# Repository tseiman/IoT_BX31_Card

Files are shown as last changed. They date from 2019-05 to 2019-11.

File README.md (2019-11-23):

# IoT BX31 Card

IoT card for Sierra Wireless MangOH (https://mangoh.io) boards.
Connects the Sierra Wirelss  BX3105 Module via UART to the (WP) Module.
The IoT card is easy to use by using the Legato (https://legato.io) AT command interpreter.

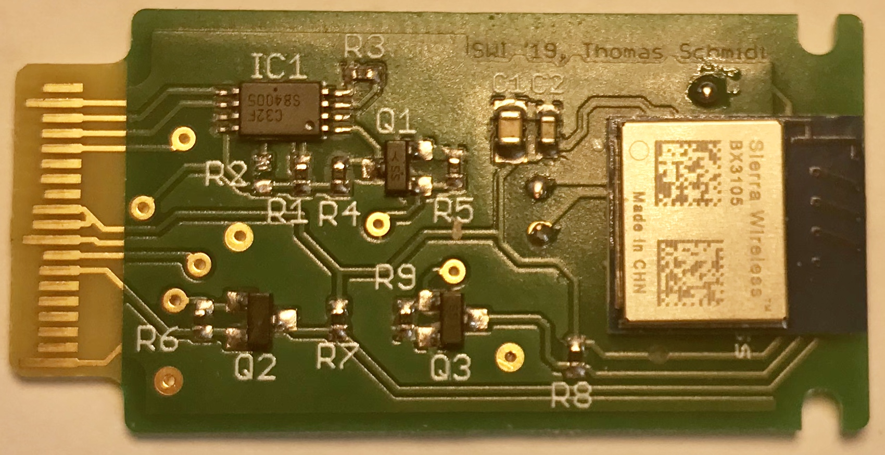
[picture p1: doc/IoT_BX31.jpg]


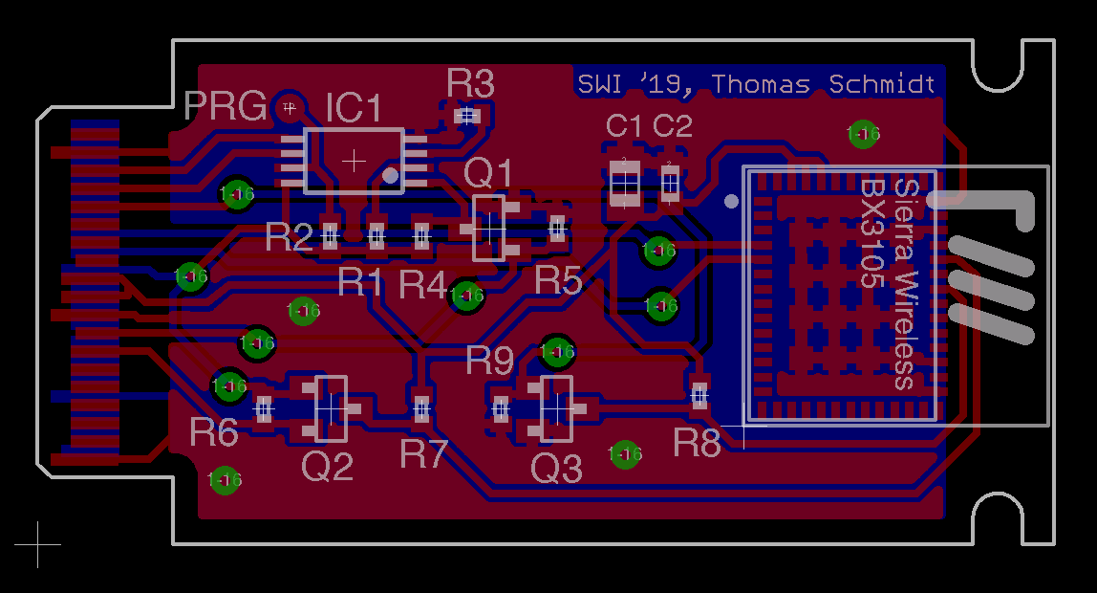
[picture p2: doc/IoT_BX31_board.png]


## Programming the EEPROM
After hardware production the EEPROM needs to be one time flashed with the Identity and configuration data of the IoT card.
Please see the eeprom folder for further information. 

## Basic testing on MangOH
Ensure that the UART of the WP module is configured correctly to handle the IoT module - e.g. by configuring it via `AT!MAPUART=17,1` command on the WP module (please cross check the WP AT User guide).
**Ensure that the GPIO's are set correctly**. On MangOH red this are GPIO 42 for Firmware update and GPIO 2 for enable. The BX31 IoT module supports update of the Firmware over UART by pulling GPIO 42 low (it is a Active Low Pin on BX3105). For normal operation **pull GPIO42 high (important)**. To reset the card you need to pull "enable" GPIO 2  High and then pull it down again - so the BX3105 gets enabled.

Disable Firmware update GPIO from command line:
```
~# echo 42 >/sys/class/gpio/export
~# echo out >/sys/class/gpio/gpio42/direction
~# echo 0 > /sys/class/gpio/gpio42/value
```
Reset the Module:
```
~# echo 2 >/sys/class/gpio/export
~# echo out >/sys/class/gpio/gpio2/direction
~# echo 1 > /sys/class/gpio/gpio2/value
~# echo 0 > /sys/class/gpio/gpio2/value
```

Now you can connect to the UART by using microcom and it should react to BX31 AT commands:
```
~# microcom -X -s 115200 /dev/ttyHS0
ATI

BX3105

OK
```
You can exit microcom by pressing **CTRL-X**. Please remember that when typing AT commands you'll not see what you type becasue BX31 are not echoing back. 

You can also read the content of the IoT card EEPROM, by reading it over I2C with i2cdump:

```
TBD
```

## Using it the IoT card in Legato

Ensure the UART of the WP module is configured in the right way. On a WP76 this can be done with the `AT!MAPUART=17,1` command. 
For further Information check the AT command guide of the Module you plan to use. 
The IoT module will be then accessible over the `/dev/ttyHS0` UART in Legato.
You might do this setoup out of a Legato application by using the Legato AT interpreter API.

In case you plan to use the BX31 IoT module in an Legato environment and to control it from a Legato Application - ensure that you have read/write access to the device.
This can be configured in the **requires - devices** section of your Legato appliactions **.adef** file - e.g.:

```
requires:
{
    device:
    {
       [rw]    /dev/ttyHS0    /dev/ttyHS0
    }
}

```

Ensure in the same file that you bind the AT Interpreter API to your project:

```
bindings:
{
    bx31_atservice.BX31_ATServiceComponent.le_atClient -> atService.le_atClient
...    
}
```

Now you can use the API to control the BX31 IoT Board - see this snippeds as some example (more glue code might be needed):

```c
        fd = le_tty_Open(BX31_SERIAL_DEVICE, O_RDWR | O_NDELAY | O_NOCTTY | O_NONBLOCK); // opening the UART2 - which is connected to the IoT Board
        if (fd == -1) {
                LE_ERROR("failed to open UART device");
                exit(EXIT_FAILURE);
        }
        
       ...

        LE_ASSERT(le_tty_SetBaudRate(fd, LE_TTY_SPEED_115200) == LE_OK);        // assuming BX31 is on 115200
        LE_ASSERT(le_tty_SetFraming(fd, 'N', 8, 1) == LE_OK);                   // set UART framing to 8bit, No Parity, 1 Stop bit
        LE_ASSERT(le_tty_SetRaw(fd, 10, 30000) == LE_OK);                       // We need raw UART mode (the canonical echo's
                                                                                // back to peer)
       ...

        DevRef = le_atClient_Start(fd);

        cmdRef = le_atClient_Create();                                          // instantiate an AT interpreter client

        /* --- check if we're really talking to BX31 --- */
        LE_INFO("Check BX310x presence");                                       // We ask for device identification string

        LE_ASSERT(le_atClient_SetCommandAndSend
                  (&cmdRef, DevRef, "ATI", "", "OK|ERROR|+CME ERROR",
                   LE_ATDEFS_COMMAND_DEFAULT_TIMEOUT) == LE_OK);

        LE_ASSERT(le_atClient_GetFinalResponse
                  (cmdRef, buffer, LE_ATDEFS_RESPONSE_MAX_BYTES) == LE_OK);

        memset(buffer, 0, 50);

        LE_ASSERT(le_atClient_GetFirstIntermediateResponse
                  (cmdRef, buffer, LE_ATDEFS_RESPONSE_MAX_BYTES) == LE_OK);

        if (strncmp(buffer, "BX310", 4) != 0) {                                 // and compare it with the expected
                LE_ERROR("This doesn seem to be a BX310x bluetooth module, "
                                "exiting. Response was \"%s\"", buffer);        // if the BT module is not answering we better exit

      ...

        LE_INFO("Disable WiFi on BX310x");                                      // here we use the BX just for BT scanning
        LE_ASSERT(le_atClient_SetCommandAndSend
                  (&cmdRef, DevRef, "AT+SRWCFG=0", "", "OK|ERROR|+CME ERROR",
                   LE_ATDEFS_COMMAND_DEFAULT_TIMEOUT) == LE_OK);

``` 

For further information please check the legato AT API https://docs.legato.io/17_09/c_atClient.html
There is also a project related to this IoT Board which is used to do a bluetooth scanning: 
https://github.com/tseiman/SWILegatoBTScanner_BX31_AVS

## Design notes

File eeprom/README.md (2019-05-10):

**eeprom_iot_bx31_card.yaml** is a template file from which the IoT Card EEPROM image can be generated.

The image is only one time flashed to give the IoT Module it's identity and configuration parameters which might be read by a Legato Application or Kernel driver.

The yaml to EEPROM bin image conversion tool can be found from here:

https://github.com/mangOH/mangOH/tree/master/tools

The **writeFile2Eeprom** tool has to be cross compiled in a Legato legs environment and is meant to run directly on a WP module - in case the EEPROM is not flashed during production.

Clone and `make` Legato according to the advises from here: https://github.com/legatoproject/legato-af .

Run the Legato bin/legs environment. Change to this directory and check the Makefile. 
Adjust the Variables:

* $(WP76XX_SYSROOT)
* $(WP76XX_TOOLCHAIN_PREFIX)
* $(WP76XX_TOOLCHAIN_DIR)

At the moment it is set to be compiled for Sierra Wireless WP76XX modules. You might adjust it e.g. to
$(WP77XX_TOOLCHAIN_DIR) or similar for an other module series.

Compile the **writeFile2Eeprom** by `make` in this folder. 

Copy the compiled **writeFile2Eeprom** e.g. by `~> scp writeFile2Eeprom root@192.168.2.2:~`.

Insert a new, unflashed IoT card into the IoT slot of a MangOH board. 
Enable the EEPROM to write. For that the WP Signal of the EEPROM needs to be pulled down. On BX31 IoT Board hardware revision 1.0 the wire 
between R5 and the EEPROM has to be conencted to GND. On newer hardware revisions there is a testpoint which needs to be connected to GND.

Run **writeFile2Eeprom** with a correct set of parameters:

```
writeFile2Eeprom [-b <busID>] -f <eeprom image input file> [-y] -s <IoT card serial Number>
    -b <busID>                     optional,  the I2C bus ID - on MangOH red it is 5 (default)
    -f <eeprom image input file>   mandatory, the image which should be written to eeprom
    -y 	                           optional,  it will not ask if you are really sure
    -s <IoT Serial Number>         mandatory, a string with max 31 bytes with the serial information
                                   of the IoT card. BX31 IoT card SN should have following format:
                                   YYYYMMDDhhmmss_<HW Version>_<NumberInBatch> e.g.: 20190506200700_1.0_001
```

e.g.: `~> writeFile2Eeprom -b 5 -f eeprom_iot_bx31_card.img -s 20190506200700_1.0_001`

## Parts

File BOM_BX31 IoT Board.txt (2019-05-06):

Stückliste exportiert aus /Users/tseiman/Documents/eagle/BX3105 IoT card/BX31 IoT Board.sch am 06.05.19 12:54

Qty Value                       Device     Package Parts                              Description                                                                   MF MPN            OC_FARNELL OC_NEWARK TP_SIGNAL_NAME
1                               C-EUC0603K C0603K  C2                                 CAPACITOR, European symbol                                                                                                         
9   10k                         R-EU_R0402 R0402   R1, R2, R3, R4, R5, R6, R7, R8, R9 RESISTOR, European symbol                                                                                                          
1   22u                         C-EUC0805K C0805K  C1                                 CAPACITOR, European symbol                                                                                                         
3   BSS138                      BSS123     SOT23   Q1, Q2, Q3                         N-CHANNEL MOS FET                                                                                                                  
1   BX3105                      BX3105     BX3105  MODULE1                            The BX310x is a low power, 802.11 b/g/n Wi-Fi and Bluetooth 4.2 combo module.                                                      
1   CAT24C32             YI-GT3 24C64ST    TSSOP8  IC1                                Serial EEPROM                                                                    CAT24C64YI-GT3 1718133    08R5418                 
1   IOT                         IOT        IOT     U$1                                IoT Expansion Card                                                                                                                 
1   TPSB1,27                    TPSB1,27   B1,27   PRG                                TEST PIN

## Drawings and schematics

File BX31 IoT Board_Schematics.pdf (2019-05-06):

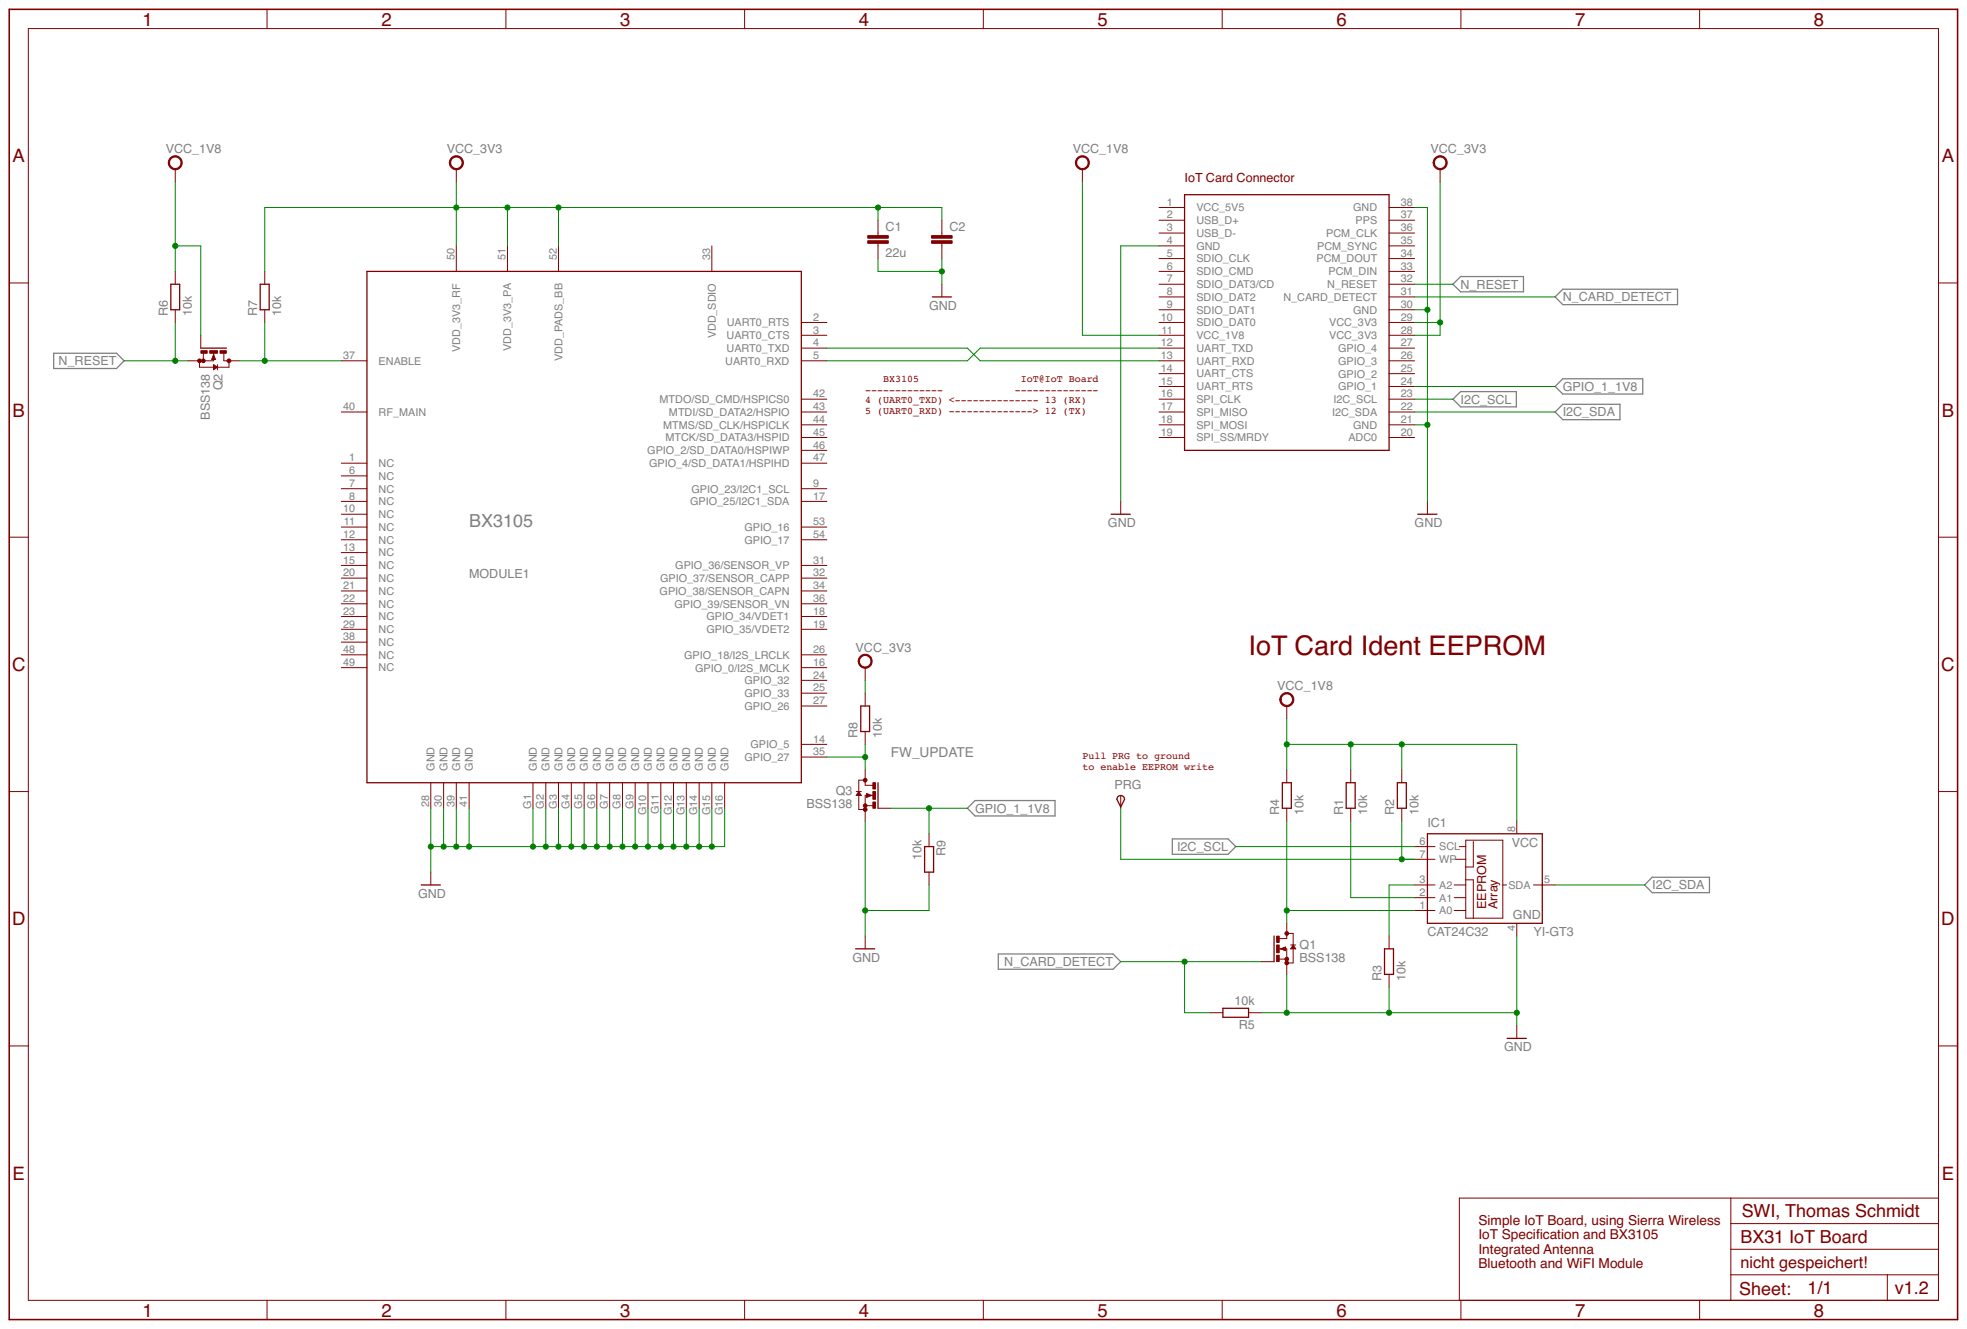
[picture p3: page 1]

IoT Card Ident EEPROM

41 GND G1 GND G2 GND G3 GND G4 GND G5 GND G6 GND G7 GND G8 GND G9 GND G11 GND G10 GND G12 GND G13 GND G14 GND G15 GND G16 GPIO_27

Pull PRG to ground
to enable EEPROM write
PRG

SWI, Thomas Schmidt Simple IoT Board, using Sierra Wireless
IoT Specification and BX3105
Integrated Antenna Bluetooth and WiFI Module

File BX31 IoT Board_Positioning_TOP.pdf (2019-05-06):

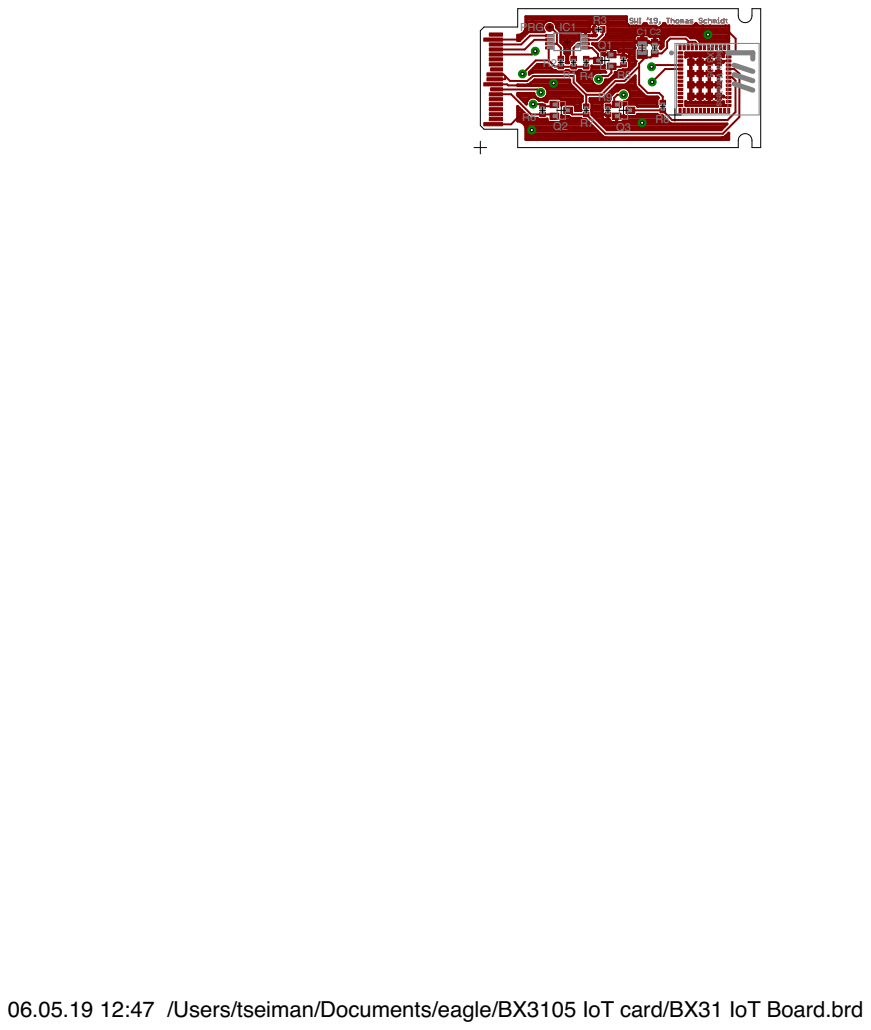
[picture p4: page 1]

06.05.19 12:47 /Users/tseiman/Documents/eagle/BX3105 IoT card/BX31 IoT Board.brd

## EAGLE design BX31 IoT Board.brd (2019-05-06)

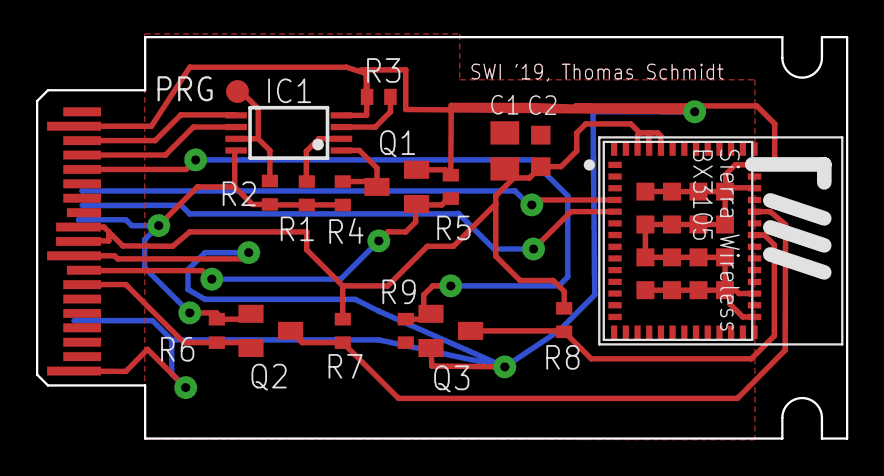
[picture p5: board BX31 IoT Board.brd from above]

Board: 2 copper layers, 45.0 x 22.3 mm, 18 parts (0 on the bottom side), 16 nets.

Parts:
C1: 22u; C0805K
C2: C0603K
IC1: CAT24C32 YI-GT3; TSSOP8
MODULE1: BX3105
PRG: TPSB1,27; B1,27
Q1, Q2, Q3: BSS138; SOT23
R1, R2, R3, R4, R5, R6, R7, R8, R9: 10k; R0402
U$1: IOT

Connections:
BX-RX_IOT-TX: MODULE1.5, U$1.12
BX-TX_IOT-RX: MODULE1.4, U$1.13
EEPROM_A0: IC1.1, Q1.3, R4.1
EEPROM_A1: IC1.2, R1.1
EEPROM_A2: IC1.3, R3.2
EEPROM_WP: IC1.7, PRG.TP, R2.1
ENABLE: MODULE1.37, Q2.3, R7.1
FW_UPDATE: MODULE1.35, Q3.3, R8.1
GND: C1.2, C2.2, IC1.4, MODULE1.28, MODULE1.30, MODULE1.39, MODULE1.41, MODULE1.G1, MODULE1.G2, MODULE1.G3, MODULE1.G4, MODULE1.G5, MODULE1.G6, MODULE1.G7, MODULE1.G8, MODULE1.G9, MODULE1.G10, MODULE1.G11, MODULE1.G12, MODULE1.G13, MODULE1.G14, MODULE1.G15, MODULE1.G16, Q1.2, Q3.2, R3.1, R5.1, R9.2, U$1.4, U$1.21, U$1.30, U$1.38
GPIO_1_1V8: Q3.1, R9.1, U$1.24
I2C_SCL: IC1.6, U$1.23
I2C_SDA: IC1.5, U$1.22
N_CARD_DETECT: Q1.1, R5.2, U$1.31
N_RESET: Q2.2, R6.1, U$1.32
VCC_1V8: IC1.8, Q2.1, R1.2, R2.2, R4.2, R6.2, U$1.11
VCC_3V3: C1.1, C2.1, MODULE1.50, MODULE1.51, MODULE1.52, R7.2, R8.2, U$1.28, U$1.29

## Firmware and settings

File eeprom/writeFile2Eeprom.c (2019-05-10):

/**
 * by Thomas Schmidt Fr 09 Mai 2019 22:59:50 CEST
 * Tool to write the IoT EEPROM directly on an MangOH board.
 * EEPROM Write needs to be enabled (see IoT Board Readme and tool Readme)
 *
 **/


#include <unistd.h>
#include <stdio.h>
#include <stdlib.h>
#include <linux/i2c-dev.h>
#include <linux/limits.h>
#include <sys/ioctl.h>
#include <sys/types.h>
#include <sys/stat.h>
#include <fcntl.h>
#include <ctype.h>
#include <string.h>


#define DEFAULT_MANGOH_RED_IOT_I2C_BUS_ID	5
#define I2C_BASE_PATH				"/dev/i2c-"
#define MAX_SN_LEN 				32
#define EEPROM_SIZE				4096

#define SERIAL_NR_START_OFFSET			70
#define SERIAL_NR_STOP_OFFSET			101





int writeEeprom(char *fileName, char* deviceName, char *serialStr) {
    FILE *infile;
    unsigned char buffer[1] = "\0";
    int lenOfSnStr = strnlen(serialStr, MAX_SN_LEN);
    int snPos = 0;
    int device;
    unsigned char data[3];

    if ((infile = fopen(fileName, "rb")) < 0) {
	perror("ERROR: cannot open image file.");
	return 0;
    } 

    printf("\n");
    
    if ((device = open(deviceName, O_RDWR)) < 0) {
	perror("Can not open I2C Bus");
	return 200;
    }
    if (ioctl(device, I2C_SLAVE, 0x53) < 0) {
	perror("Can not connect to Device");
	return 201;
    }

    for(int i = 0; i < EEPROM_SIZE; ++i) {
	fread(&buffer, sizeof(unsigned char), 1, infile);
	if(i >= SERIAL_NR_START_OFFSET && i <= SERIAL_NR_STOP_OFFSET && snPos <= lenOfSnStr) {
	    buffer[0] = serialStr[snPos];
	    ++snPos;
	} 


	data[0]= (unsigned char) (i >> 8);	// High Byte Address
	data[1]= (unsigned char) i; 		// Low Byte Address
	data[2]= (unsigned char) buffer[0];	// Data Byte
	write(device,data,3);
	printf("\033[sWrite %d%% : addr %02x %02x , data= %x\033[u", i*100/EEPROM_SIZE+1, data[0], data[1], data[2]);
	usleep(5000);
    }
    printf("\n");

    close(device);
    fclose(infile);

    return 1;

} 


int checkEepromImgFileHeader(char *fileName) {
    FILE *fp;
    struct stat st;
    stat(fileName, &st);
    if(st.st_size != EEPROM_SIZE) return 0;
    unsigned char buffer[1] = "\0";

    if ((fp = fopen(fileName, "rb")) < 0) {
	perror("ERROR: cannot open image file.");
	return 0;
    } 
    fread(&buffer, sizeof(unsigned char), 1, fp);
    if(buffer[0] != 0xaa) return 0;

    fread(&buffer, sizeof(unsigned char), 1, fp);
    if(buffer[0] != 0x55) return 0;

    fclose(fp);
    return 1;
}



int main (int argc, char **argv) {

    char deviceName[PATH_MAX];
    char *inputFile = NULL;
    int busID = DEFAULT_MANGOH_RED_IOT_I2C_BUS_ID;
    int c;
    int noInteractive = 0;
    char securityQuestion;
    char serialString[MAX_SN_LEN];
    opterr = 0;

    memset(serialString,0,MAX_SN_LEN);

    while ((c = getopt (argc, argv, "b:f:s:hy")) != -1) {
	switch (c) {
    	    case 'b':
		for (int i=0;i< strlen(optarg); i++) {
    		    if (!isdigit(optarg[i])) {
        		printf ("ERROR: input for BusID is not a number\n");
        		return 1;
    		    }
		}
    		busID = atoi(optarg);
    		break;
    	    case 'f':
    		inputFile = optarg;
    		break;
    	    case 's':
    		if(strlen(optarg) > MAX_SN_LEN - 1) {
		    fprintf (stderr, "ERROR: serial number string too long - max len is %d - but actually given len is %d\n", MAX_SN_LEN -1 , (int)strlen(optarg));
		    return 1;
		}
		strncpy(serialString,optarg,MAX_SN_LEN -1);
    		break;
    	    case 'y':
    		noInteractive = 1;
    		break;
    	    case 'h':
    		printf("usage writeFile2Eeprom [-b <busID>] -f <eeprom image input file> [-y] -s <IoT card serial Number> \n");
    		printf("    -b <busID>                     optional,  the I2C bus ID - on MangOH red it is 5 (default)\n");
    		printf("    -f <eeprom image input file>   mandatory, the image which should be written to eeprom\n");
    		printf("    -y 	                           optional,  it will not ask if you are really sure\n");
    		printf("    -s <IoT Serial Number>         mandatory, a string with max 31 bytes with the serial information\n");
		printf("                                   of the IoT card. BX31 IoT card SN should have following format:\n");
		printf("                                   YYYYMMDDhhmmss_<HW Version>_<NumberInBatch> e.g.: 20190506200700_1.0_001\n");
		return 0;
    	    case '?':
    		if (optopt == 'f' || optopt == 'b') {
		    fprintf (stderr, "ERROR: Option -%c requires an argument.\n", optopt);
    		} else if (isprint (optopt)) {
        	    fprintf (stderr, "ERROR: Unknown option `-%c'.\n", optopt);
    		} else {
        	    fprintf (stderr, "ERROR: Unknown option character `\\x%x'.\n", optopt);
		}
		return 1;
    	    default:
    		abort ();
        }
    }

    if(access( inputFile , F_OK ) == -1 ) {
	fprintf(stderr,"Error: File %s - not found or readable.\n", inputFile);
	return 2;
    }

    if(strnlen(serialString,MAX_SN_LEN) < 1) {
	fprintf(stderr,"Error: Serial string %s - not correct.\n", serialString);
	return 4;

    }

    sprintf(deviceName, "%s%d", I2C_BASE_PATH, busID);

    if(! checkEepromImgFileHeader(inputFile)) {
	fprintf(stderr,"Error: File %s - doesn't seem to be a IoT card EEPROm image file.\n", inputFile);
	return 5;
    }

    printf("Please check carefully:\n");
    printf("  input file        =  %s\n", inputFile);
    printf("  I2C device Name   =  %s\n", deviceName);
    printf("  Device Serial ID  =  %s\n", serialString);
    
    if(!noInteractive) {
	do {
	    printf("Are you really sure to write to this device ? y/n: "); 
	    fflush(stdin);
    	    scanf(" %c",&securityQuestion);
	} while ( securityQuestion != 'n' && securityQuestion != 'y');
	if(securityQuestion == 'n') return 0; 
    }
    
    if(! writeEeprom(inputFile, deviceName, serialString)) { 
	fprintf(stderr,"Error: Failed to process image.\n");
	return 254;
    }

    printf("Successfuly wrote image.\n");
    
}

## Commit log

2019-05-06 Delete BX31 IoT Board MULTI_BOTTOM_Copper.pdf
    Delete Multi PDFs
2019-05-06 Delete BX31 IoT Board MULTI_BUTTOM_Stop.pdf
    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
2019-05-06 Delete BX31 IoT Board MULTI_TOP_Copper.pdf
    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
2019-05-06 Delete BX31 IoT Board MULTI_TOP_Stop.pdf
    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
2019-05-06 Delete BX31 IoT Board MULTI.brd
    Delete Multi Board
    [BX31 IoT Board MULTI.brd]
2019-05-06 removed multi
    [BX31 IoT Board.brd, BX31 IoT Board.sch]
2019-05-06 removed BX31 Pin 33 supply, added testpoint for EEPROM, fixerd layout
    [BX31 IoT Board.brd]
2019-05-06 Delete BX31 IoT Board_SOLDER-CREAM_BOTTOM.pdf
    Remove solder masks
2019-05-06 Delete BX31 IoT Board_SOLDER-CREAM_BOTTOM_NEG.pdf
    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
2019-05-06 Delete BX31 IoT Board_SOLDER-CREAM_TOP.pdf
    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
2019-05-06 Delete BX31 IoT Board_SOLDER-CREAM_TOP_NEG.pdf
    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
2019-05-06 Delete BX31 IoT Board_SOLDER_TOP.pdf
    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
2019-05-06 Delete BX31 IoT Board.s##
    cleanup
